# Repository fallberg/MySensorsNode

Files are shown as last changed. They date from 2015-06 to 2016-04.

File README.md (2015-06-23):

# MySensorsNode
My personal [MySensors](http://mysensors.org) Node HW designs.
All designs are released under the [CERN Open Hardware Licence v1.2](http://ohwr.org/cernohl).

External dependencies:
- KiCad
- Non-standard libraries:
  - Mysensors repositories (https://github.com/mysensors-kicad)
  - Walter Lain's KiCad libraries (http://smisioto.no-ip.org/elettronica/kicad/kicad-en.htm)

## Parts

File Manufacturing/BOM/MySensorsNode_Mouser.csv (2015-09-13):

Count | Reference | Value | Footprint | Datasheet | Vendor | Vendor part | Supplier | Supplier part | Supplier link
1 | ANT1 | CONN_01X01 | Wire_Pads:SolderWirePad_single_1-2mmDrill |  |  |  | Missing | Missing | Missing
1 | BT1 | 2.5mm jack | mysensors_connectors:dc_socket-kcswalter | http://www.mouser.com/ds/2/393/rapc712x_cd-371318.pdf | Switchcraft | RAPC712X | Mouser | 502-RAPC712X | http://www.mouser.com/ProductDetail/Switchcraft/RAPC712X/
1 | BT2 | JST | mysensors_connectors:s2b-ph-kl-kcswalter | http://www.farnell.com/datasheets/80564.pdf | JST | S2B-PH-K-S (LF)(SN) | Missing | Missing | Missing
1 | BT3 | Generic | mysensors_connectors:TerminalBlock2.54mmx2-kcswalter | http://www.mouser.com/ds/2/418/NG_CD_282834_C1-665080.pdf | TE Connectivity | 282834-2 | Mouser | 571-282834-2 | http://www.mouser.se/ProductDetail/TE-Connectivity/282834-2/
1 | BT4 | CR123 | mysensors_connectors:CR123_holder | http://www.mouser.com/ds/2/215/051-743208.pdf | Keystone Electronics | 1051 | Mouser | 534-1051 | http://www.mouser.se/ProductDetail/Keystone-Electronics/1051/?Keystone-Electronics%2f1051%2f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
1 | BT5 | 24.5mm | mysensors_connectors:keystone_3009-kcswalter | http://www.mouser.com/ds/2/215/3039-285159.pdf | Keystone Electronics | 3039 | Mouser | 534-3039 | http://se.mouser.com/ProductDetail/Keystone-Electronics/3039/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
1 | C1 | 47uF | Capacitors_Tantalum_SMD:TantalC_SizeC_EIA-6032_HandSoldering | http://www.avx.com/docs/Catalogs/tps.pdf | AVX | TPSC476K016R0350 | Mouser | 581-TPSC476K016R0350 | http://se.mouser.com/ProductDetail/AVX/TPSC476K016R0350/?qs=sGAEpiMZZMuEN2agSAc2pqveSFvydLQ7xWNXjpUWqVg%3d
5 | C2 C10 C12 C13 C14 | 4.7uF | Capacitors_Tantalum_SMD:TantalC_SizeB_EIA-3528_HandSoldering | http://www.avx.com/docs/Catalogs/tps.pdf | AVX | TPSB475K025R0900 | Mouser | 581-TPSB475K025R0900 | http://se.mouser.com/ProductDetail/AVX/TPSB475K025R0900/?qs=sGAEpiMZZMuEN2agSAc2pkIWJcW2hAciBvjiIg4pnBc%3d
2 | C3 C4 | 10uF | Capacitors_Tantalum_SMD:TantalC_SizeA_EIA-3216_HandSoldering | http://www.mouser.com/ds/2/40/f93-221107.pdf | AVX | F931C106MAA | Mouser | 647-F931C106MAA | http://www.mouser.se/ProductDetail/AVX/F931C106MAA/?qs=sGAEpiMZZMuEN2agSAc2puC4lhRhLeolmYomTIpwaLE%3d
2 | C5 C6 | 10uF | Capacitors_SMD:C_1206_HandSoldering | http://www.mouser.com/ds/2/427/vjw1bcbascomseries-223529.pdf | Vishay / Vitramon | VJ1206V106ZXQTW1BC | Mouser | 77-VJ1206V106ZXQTBC | http://se.mouser.com/Search/ProductDetail.aspx
6 | C7 C11 C15 C16 C17 C18 | 0.1uF | Capacitors_SMD:C_1206_HandSoldering | http://www.farnell.com/datasheets/1825494.pdf | MULTICOMP | MCSH31B104K250CT | Mouser | 77-VJ1206Y104KXQPBC | http://se.mouser.com/ProductDetail/Vishay-Vitramon/VJ1206Y104KXQPW1BC/
1 | C8 | C | Resistors_Universal:Resistor_SMD+THTuniversal_0805to1206_RM10_HandSoldering |  | User specific |  | Missing | Missing | Missing
1 | C9 | 0.1uF | Capacitors_SMD:C_1206_HandSoldering | http://www.mouser.com/ds/2/427/vjw1bcbascomseries-223529.pdf | Vishay | VJ1206Y104KXXCW1BC | Mouser | 77-VJ1206Y104KXXCBC | http://www.mouser.se/ProductDetail/Vishay-Vitramon/VJ1206Y104KXXCW1BC/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
7 | JP1 JP3 JP4 JP5 JP6 JP7 JP10 | Jumper_NO_Small | Pin_Headers:Pin_Header_Straight_1x02 | https://www1.elfa.se/data1/wwwroot/assets/datasheets/cgrid_III_90120_eng_dwg.pdf | Wurth Electronics | 61300211121 | Mouser | 710-61300211121 | http://www.mouser.com/ProductDetail/Wurth-Electronics/61300211121/
3 | JP2 JP8 JP9 | JUMPER3 | Pin_Headers:Pin_Header_Straight_1x03 | http://www.mouser.com/ds/2/1/3m_ts0816-349901.pdf | HARWIN | M20-9990346 | Mouser | 517-9611036804AR | http://www.mouser.com/ProductDetail/3M-Electronic-Solutions-Division/961103-6804-AR/
1 | L1 | 4.7uH | Capacitors_SMD:C_0805_HandSoldering | http://www.yuden.co.jp/productdata/catalog/en/wound02_e.pdf | Taiyo Yuden | CBC2012T4R7M | Mouser | 963-CBC2012T4R7M | http://se.mouser.com/ProductDetail/Taiyo-Yuden/CBC2012T4R7M/
1 | P1 | MYSX_1.5 | mysensors_connectors:MYSX_1.5 | http://www.mouser.com/ds/2/181/M20-998-351176.pdf | HARWIN | M20-9981045 | Mouser | 855-M20-9981045 | http://www.mouser.se/ProductDetail/Harwin/M20-9981045/
1 | P2 | CONN_02X03 | Pin_Headers:Pin_Header_Straight_2x03 | http://www.farnell.com/datasheets/1712126.pdf | HARWIN | M20-9980346 | Mouser | 855-M20-9980346 | http://www.mouser.se/ProductDetail/Harwin/M20-9980346/
2 | P3 P4 | CONN_01X03 | Pin_Headers:Pin_Header_Straight_1x03 | http://www.mouser.com/ds/2/1/3m_ts0816-349901.pdf | HARWIN | M20-9993646 | Mouser | 517-9611036804AR | http://www.mouser.com/ProductDetail/3M-Electronic-Solutions-Division/961103-6804-AR/
2 | Q1 Q2 | DMP3056L-7 | Housings_SOT-23_SOT-143_TSOT-6:SOT-23_Handsoldering | http://www.mouser.com/ds/2/115/DMP3056L-526286.pdf | Diodes Incorporated | DMP3056L-7 | Mouser | 621-DMP3056L-7 | http://www.mouser.com/ProductDetail/Diodes-Incorporated/DMP3056L-7/
1 | R1 | 150K | Resistors_SMD:R_0805_HandSoldering | http://www.farnell.com/datasheets/1581132.pdf | Vishay / Dale | CRCW0805150KFKEA | Mouser | 71-CRCW0805-150K-E3 | http://se.mouser.com/ProductDetail/Vishay-Dale/CRCW0805150KFKEA/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
4 | R2 R3 R4 R5 | 10K | Resistors_SMD:R_0805_HandSoldering | https://www1.elfa.se/data1/wwwroot/assets/datasheets/flD-CRCW-e3_data_en.pdf | Vishay | CRCW080510K0FKEA | Mouser | 754-RR1220P-103D | http://se.mouser.com/Search/ProductDetail.aspx
4 | R6 R7 R8 R9 | 56K | Resistors_SMD:R_0805_HandSoldering | https://www1.elfa.se/data1/wwwroot/assets/datasheets/flD-CRCW-e3_data_en.pdf | Panasonic | ERJP06F5602V | Mouser | 754-RR1220P-563D | http://se.mouser.com/ProductDetail/Susumu/RR1220P-563-D/
1 | RV1 | 1M | Potentiometers:Potentiometer_Bourns_3296Y_3-8Zoll_Angular_ScrewUp | http://www.farnell.com/datasheets/1815117.pdf | BOURNS | 3296Y-1-105LF | Mouser | 652-3296Y-1-105LF | http://se.mouser.com/ProductDetail/Bourns/3296Y-1-105LF/?qs=sGAEpiMZZMvygUB3GLcD7sSg8po3Zpo3B4ds1vJ8JQM%3d
1 | U1 | LD1117DT33TR | mysensors_obscurities:d-pak-kcswalter | http://www.st.com/st-web-ui/static/active/en/resource/technical/document/datasheet/CD00000544.pdf | STMicroelectronics | LD1117DT33TR | Mouser | 511-LD1117DT33-TR | http://se.mouser.com/ProductDetail/STMicroelectronics/LD1117DT33TR/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
1 | U2 | TPS61097A | mysensors_handsoldering:SOT-23-5_Handsoldering | http://www.ti.com/lit/ds/symlink/tps61097a-33.pdf | Texas Instruments | TPS61097A-33DBVT | Mouser | 595-TPS61097A-33DBVT | http://www.mouser.com/ProductDetail/Texas-Instruments/TPS61097A-33DBVT/
1 | U3 | ATSHA204A | Housings_SOT-23_SOT-143_TSOT-6:SOT-23_Handsoldering | http://www.mouser.com/ds/2/36/Atmel-8885-CryptoAuth-ATSHA204A-Datasheet-336392.pdf | Atmel | ATSHA204A | Mouser | 566-ATSHA204ASTUCZ-T | http://www.mouser.com/Search/ProductDetail.aspx
1 | U4 | RFM69HW | mysensors_radios:RFM69HW_SMD_ThroughHole_Handsoldering | http://modtronicsaustralia.com/wp-content/uploads/2014/11/RFM69HW-V1.3.pdf | HOPE Microelectronics | RFM69HW | Missing | Missing | Missing
1 | U5 | NRF24L01 | mysensors_radios:NRF24L01 | http://www.farnell.com/datasheets/1697510.pdf | MULTICOMP | 2214S-08SG-85 | Mouser | 517-929975-01-04-RK | http://www.mouser.com/ProductDetail/3M-Electronic-Solutions-Division/929975-01-04-RK/
1 | U6 | AT25DF512C | Housings_SOIC:SOIC-8_3.9x4.9mm_Pitch1.27mm | http://www.mouser.com/ds/2/590/DS-AT25DF512C-030-534014.pdf | Adesto Technologies | AT25DF512C-SSHN-B | Mouser | 988-AT25DF512CSSHN-B | http://www.mouser.com/Search/ProductDetail.aspx
1 | U7 | ArduinoProMini | mysensors_arduino:pro_mini | http://www.arduino.cc/en/uploads/Main/Arduino-Pro-Mini-schematic.pdf | Arduino | Pro Mini (China model) | Missing | Missing | Missing
1 | U8 | Si7021 | Housings_DFN_QFN:DFN-6-1EP_3x3mm_Pitch0.95mm | https://www.silabs.com/Support%20Documents/TechnicalDocs/Si7021-A20.pdf | Silicon Labs | Si7021-A20-GM1 | Mouser | 634-SI7021-A20-GM1 | http://se.mouser.com/ProductDetail/Silicon-Laboratories/Si7021-A20-GM1/
1 | U9 | TPS61221 | Housings_SOT-23_SOT-143_TSOT-6:SC-70-6 | http://www.ti.com/lit/gpn/tps61221 | Texas Instruments | TPS61221DCK | Mouser | 595-TPS61221DCKR | http://www.mouser.se/ProductDetail/Texas-Instruments/TPS61221DCKR/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

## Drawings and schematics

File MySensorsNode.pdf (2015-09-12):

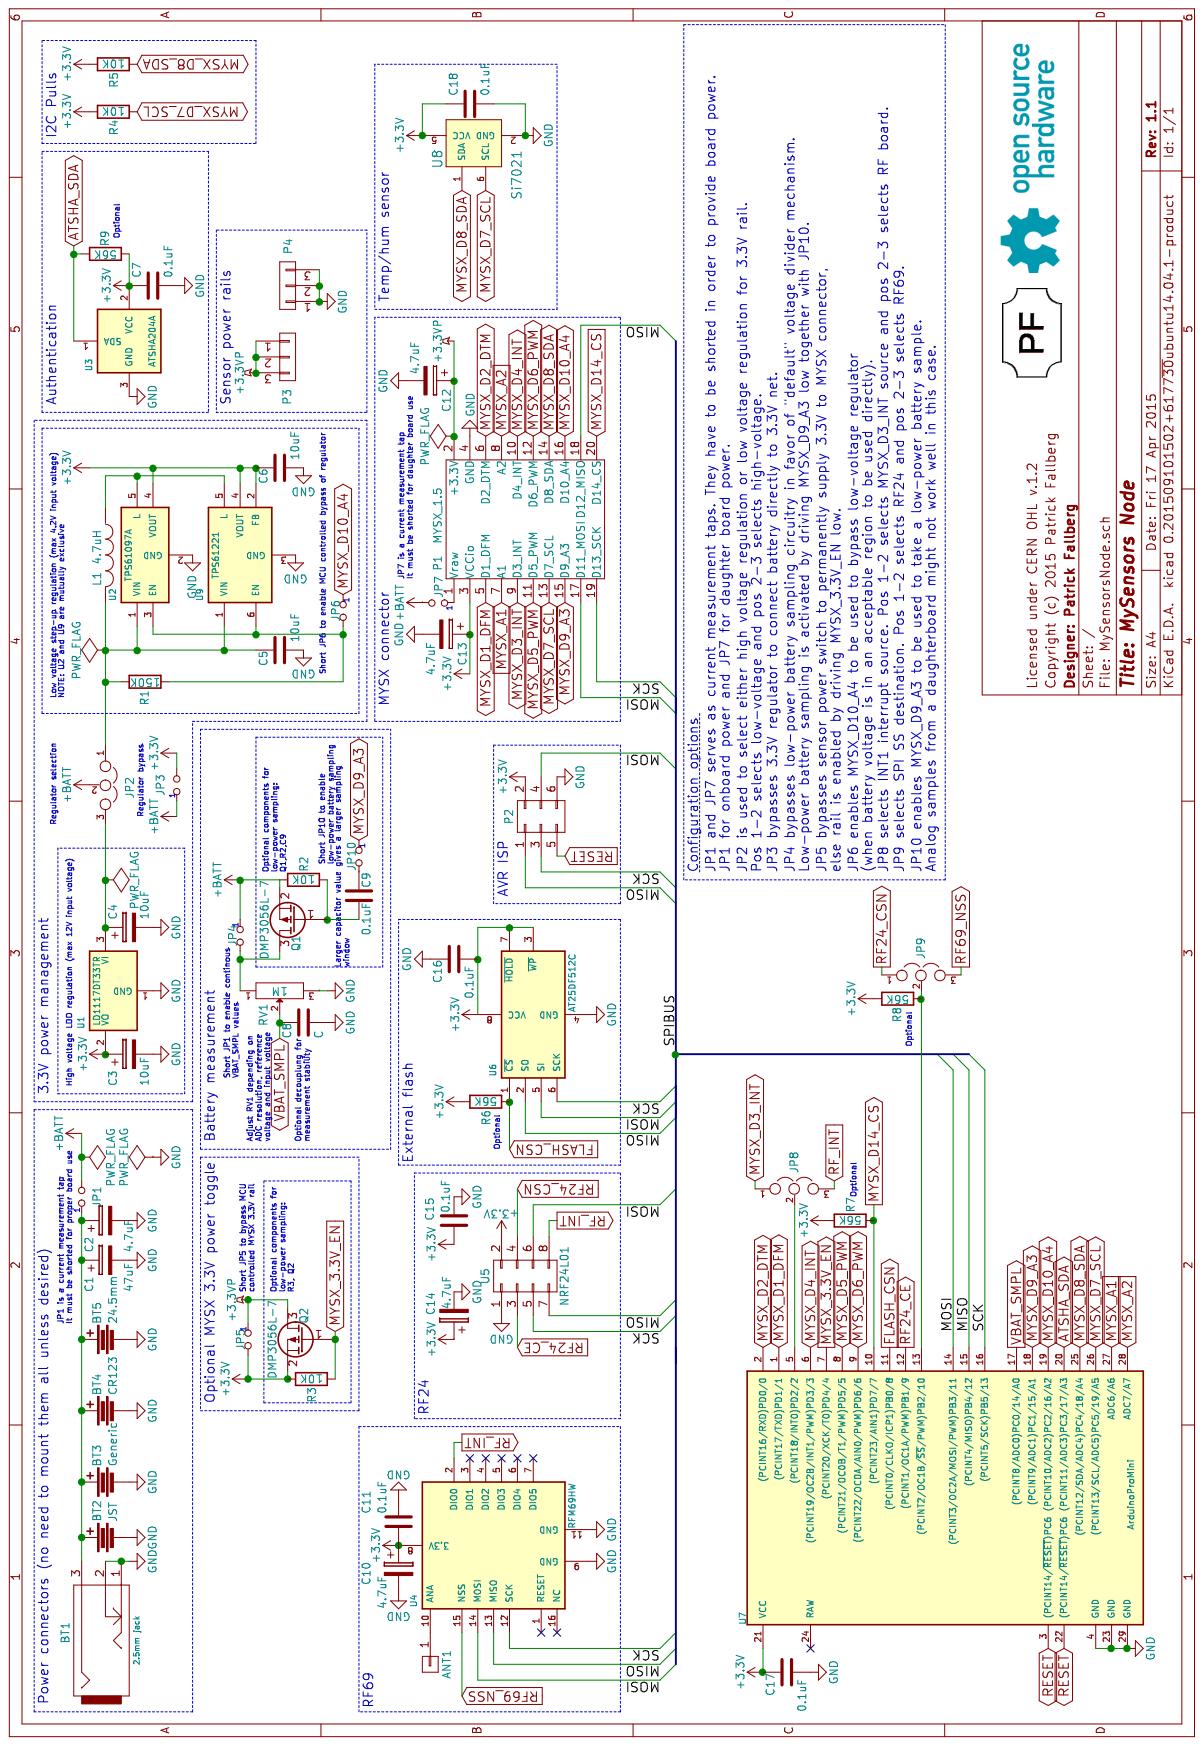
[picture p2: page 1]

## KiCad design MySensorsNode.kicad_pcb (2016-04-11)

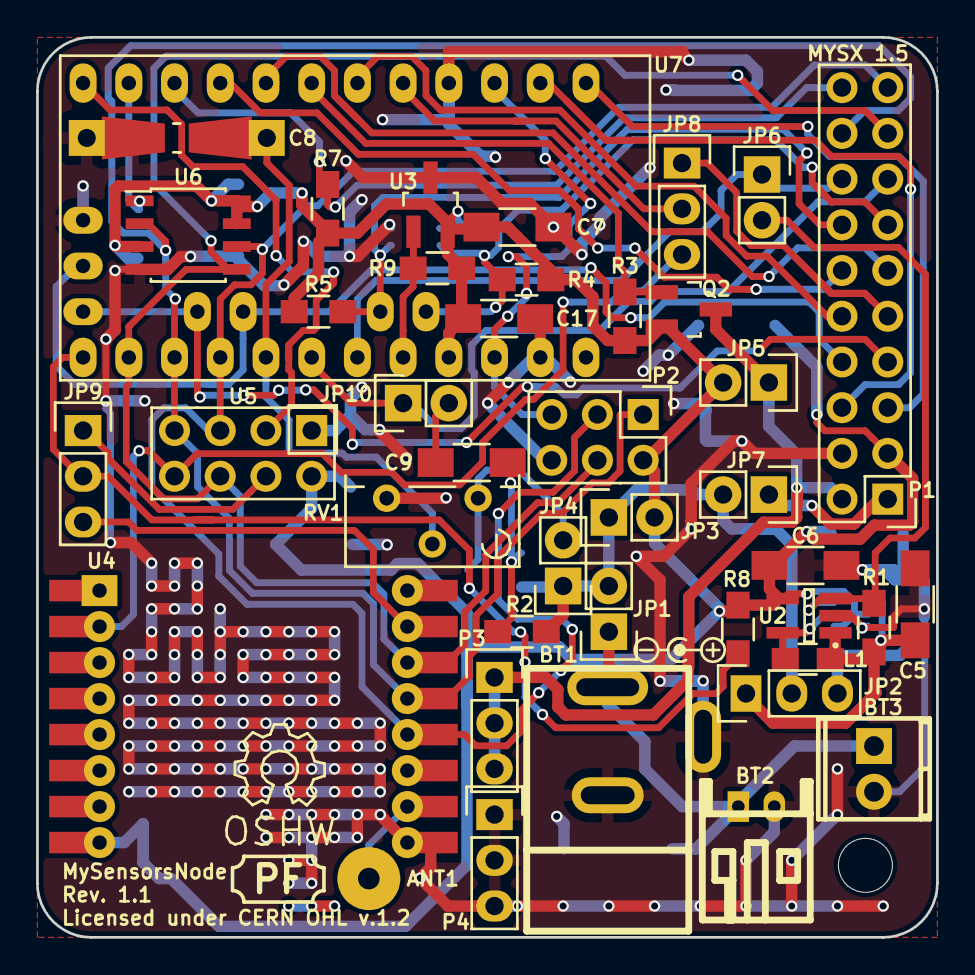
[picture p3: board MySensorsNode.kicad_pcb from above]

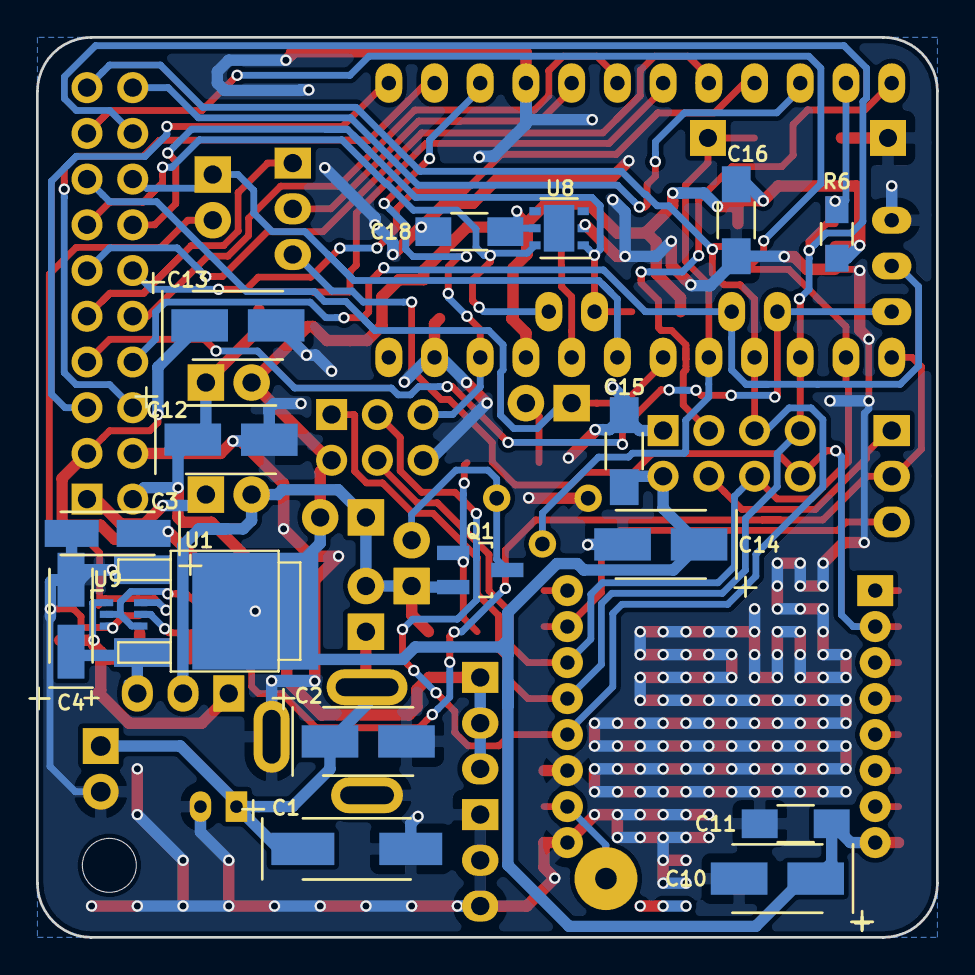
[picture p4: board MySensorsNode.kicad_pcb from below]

Board: 2 copper layers, 50.0 x 50.0 mm, 61 parts (17 on the bottom side), 41 nets.

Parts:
ANT1: CONN_01X01; SolderWirePad_single_1-2mmDrill
BT1: 2.5mm jack; dc_socket-kcswalter
BT2: JST; s2b-ph-kl-kcswalter
BT3: Generic; TerminalBlock2.54mmx2-kcswalter
C1: 47uF; TantalC_SizeC_EIA-6032_HandSoldering
C2, C10, C12, C13, C14: 4.7uF; TantalC_SizeB_EIA-3528_HandSoldering
C3, C4: 10uF; TantalC_SizeA_EIA-3216_HandSoldering
C5, C6: 10uF; C_1206_HandSoldering
C7, C9, C11, C15, C16, C17, C18: 0.1uF; C_1206_HandSoldering
C8: C; Resistor_SMD+THTuniversal_0805to1206_RM10_HandSoldering
HOLE1: MountingHole_3mm
JP1, JP3, JP4, JP5, JP6, JP7, JP10: Jumper_NO_Small; Pin_Header_Straight_1x02
JP2, JP8, JP9: JUMPER3; Pin_Header_Straight_1x03
L1: 4.7uH; C_0805_HandSoldering
OSHW_LOGO: Symbol_OSHW-Logo_SilkScreen
P1: MYSX_1.5
P2: CONN_02X03; Pin_Header_Straight_2x03
P3, P4: CONN_01X03; Pin_Header_Straight_1x03
PLUG_SPEC: LOGO; Logo_silk_polarity_center_5x1.4mm
Q1, Q2: DMP3056L-7; SOT-23_Handsoldering
R1: 150K; R_0805_HandSoldering
R2, R3, R4, R5: 10K; R_0805_HandSoldering
R6, R7, R8, R9: 56K; R_0805_HandSoldering
RV1: 1M; Potentiometer_Bourns_3296Y_3-8Zoll_Angular_ScrewUp
U1: LD1117DT33TR; d-pak-kcswalter
U2: TPS61097A; SOT-23-5_Handsoldering
U3: ATSHA204A; SOT-23_Handsoldering
U4: RFM69HW; RFM69HW_SMD_ThroughHole_Handsoldering
U5: NRF24L01
U6: AT25DF512C; SOIC-8_3.9x4.9mm_Pitch1.27mm
U7: ArduinoProMini; pro_mini
U8: Si7021; DFN-6-1EP_3x3mm_Pitch0.95mm
U9: TPS61221; SC-70-6

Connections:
+3.3VP: C12.1, JP5.1, P1.2, P3.1, P3.2, P3.3, Q2.3
+3V3: C3.1, C6.1, C7.1, C10.1, C11.2, C13.1, C14.1, C15.2, C16.2, C17.1, C18.1, JP3.2, JP5.2, P1.3, P2.2, Q2.2, R3.2, R4.2, R5.2, R6.2, R7.2, R8.1, R9.2, U1.2, U2.4, U3.2, U4.8, U5.2, U6.3, U6.7, U6.8, U7.21, U8.5, U9.2, U9.4
+BATT: JP1.2, JP2.2, JP3.1, JP4.1, JP7.2, Q1.2, R2.2
/MISO: P1.18, P2.1, U4.13, U5.7, U6.2, U7.15
/MOSI: P1.17, P2.4, U4.14, U5.6, U6.5, U7.14
/SCK: P1.19, P2.3, U4.12, U5.5, U6.6, U7.16
ATSHA_SDA: R9.1, U3.1, U7.20
FLASH_CSN: R6.1, U6.1, U7.11
GND: BT1.1, BT1.2, BT2.2, BT3.2, C1.2, C2.2, C3.2, C4.2, C5.2, C6.2, C7.2, C8.2, C10.2, C11.1, C12.2, C13.2, C14.2, C15.1, C16.1, C17.2, C18.2, P1.4, P2.6, P4.1, P4.2, P4.3, RV1.3, U1.1, U2.2, U3.3, U4.9, U4.11, U5.1, U6.4, U7.4, U7.23, U7.29, U8.2, U9.3
MYSX_3.3V_EN: Q2.1, R3.1, U7.7
MYSX_A1: P1.7, U7.27
MYSX_A2: P1.8, U7.28
MYSX_D1_DFM: P1.5, U7.1
MYSX_D2_DTM: P1.6, U7.2
MYSX_D3_INT: JP8.1, P1.9
MYSX_D4_INT: P1.10, U7.6
MYSX_D5_PWM: P1.11, U7.8
MYSX_D6_PWM: P1.12, U7.9
MYSX_D7_SCL: P1.13, R4.1, U7.26, U8.6
MYSX_D8_SDA: P1.14, R5.1, U7.25, U8.1
MYSX_D9_A3: JP10.1, P1.15, U7.18
MYSX_D10_A4: JP6.1, P1.16, U7.19
MYSX_D14_CS: P1.20, R7.1, U7.10
unnamed: ANT1.1, U4.10
unnamed: BT1.3, BT2.1, BT3.1, C1.1, C2.1, JP1.1
unnamed: C4.1, JP2.3, U1.3
unnamed: C5.1, JP2.1, L1.2, R1.1, U2.1, U9.1
unnamed: C9.1, JP10.2
unnamed: C9.2, Q1.1, R2.1
unnamed: JP4.2, Q1.3, RV1.1
unnamed: JP6.2, R1.2, U2.3, U9.6
unnamed: JP7.1, P1.1
unnamed: JP8.2, U7.5
unnamed: JP9.2, R8.2, U7.13
unnamed: L1.1, U2.5, U9.5
RESET: P2.5, U7.3, U7.22
RF24_CE: U5.3, U7.12
RF24_CSN: JP9.1, U5.4
RF69_NSS: JP9.3, U4.15
RF_INT: JP8.3, U4.2, U5.8
VBAT_SMPL: C8.1, RV1.2, U7.17

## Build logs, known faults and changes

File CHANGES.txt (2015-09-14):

commit c6829e1e322eb0ecf867edcd6b73e424e8df0c89
Author: Patrick Fallberg <patrick@fallberg.net>
Date:   Sun Sep 13 15:36:56 2015 +0200

    Corrected Mouser/Farnell parts for P2

commit 2b0d06d92dfd4355a7a4b18cb5ec9ce1f207d5c6
Author: Patrick Fallberg <patrick@fallberg.net>
Date:   Sat Sep 12 22:18:08 2015 +0200

    Removed origin-symbol from board outlines

commit 1c8365d9faff273dc4cebe651df270a5b05ed6fa
Author: Patrick Fallberg <patrick@fallberg.net>
Date:   Sat Sep 12 22:10:38 2015 +0200

    Created manufacturing outputs
    
    Also created DirtyPCBs-formatted archives.
    Fixes #9

commit af362b0fcdb8be146da8d00798e79c5897116803
Author: Patrick Fallberg <patrick@fallberg.net>
Date:   Sat Sep 12 22:02:41 2015 +0200

    Minor layout beautifications

commit 6da535b47e0d930e4cade6ed8c1804b414268bb9
Author: Patrick Fallberg <patrick@fallberg.net>
Date:   Sat Sep 12 17:33:58 2015 +0200

    Created BOM(s)
    
    Fixes #10

commit 09b7c4b18d3ffa5ed8908088ca1046db3e48c771
Author: Patrick Fallberg <patrick@fallberg.net>
Date:   Sat Sep 12 17:27:01 2015 +0200

    Created a BOM generator script for this project
    
    The BOM generator (verified on KiCad for Linux) parses the netllist
    data and outputs 9 BOM files:
    MySensorsNode_Full.txt - Full BOM with all suppliers
    MySensorsNode_Cheapest.txt - BOM with the cheapest supplier
    MySensorsNode_AliExpress.txt - BOM with all parts available from AliExpress
    MySensorsNode_Digi-Key.txt - BOM with all parts available from Digi-Key
                                 This file is supported by Digi-Keys Text File
                                 Import tool.
    MySensorsNode_eBay.txt - BOM with all parts available from eBay
    MySensorsNode_Elfa.txt - BOM with all parts available from Elfa
                             This file is suppored by Elfas Own list upload tool.
    MySensorsNode_Farnell.txt - BOM with all parts available from Farnell
    MySensorsNode_Mouser.csv - BOM with all parts available from Mouser
                               This file is supported by Mousers BOM import tool.
    MySensorsNode_RS.txt - BOM with all parts available from RS Components
    
    Usage:
    Add plugin in the Bill of Material tool in the KiCad schematic editor.
    Command line is:
    python "<path to pf_bom_orders.py>" "%I" "%P/Manufacturing/BOM/%B"

commit a0b7d2081370d753c179b53b6fe635f4e56f8792
Author: Patrick Fallberg <patrick@fallberg.net>
Date:   Sat Sep 12 17:14:41 2015 +0200

    Completed sourcing details of all components
    
    Sourcing data is organized in the following way:
    Supplier1 - The primary supplier (also the cheapest)
    Supplier1 part - The primary supplier part number
    Supplier1 link - Link to the part on the suppliers homepage
    
    The same goes for Supplier2 to 5.
    All parts also have a Vendor and Vendor part field to identify
    a vendor for each part.
    
    Fixes #6

commit dedd2f74219450baf48360123f8e6970bc3806d9
Author: Patrick Fallberg <patrick@fallberg.net>
Date:   Sat Sep 12 12:29:52 2015 +0200

    Updated CR123 battery holder footprint
    
    Fixes #11

commit ceb92c99b859bb8fba81d5ead6944f00e74a0db8
Author: Patrick Fallberg <patrick@fallberg.net>
Date:   Thu Sep 10 17:14:51 2015 +0200

    Added more sourcing details
    
    Also minor schematic beautifications

commit c3afbb278e0b595ffe8860ce40d635c5186febf4
Author: Patrick Fallberg <patrick@fallberg.net>
Date:   Tue Sep 1 23:47:13 2015 +0200

    Added a step-up reg and some sourcing details
    
    Added TI TPS61221 (3.3V fixed) as an alternative to TPS61097A.
    Also added some more sourcing details to some components in the
    schematic.

commit a9de2d0fda3e2e20fb438053d0ed1dc1a1a9444a
Author: Patrick Fallberg <patrick@fallberg.net>
Date:   Mon Aug 31 10:47:24 2015 +0200

    Moved BT5 to make more room for mounting screw

commit 9ecaa06f57022bd6a6c9af58877cf1eb74a005dd
Author: Patrick Fallberg <patrick@fallberg.net>
Date:   Mon Aug 31 10:37:13 2015 +0200

    Created layout for LE-BOX-0028
    
    Fixes #8

commit 912072cc9c9a7d4f22a4622eae9dfa80e3f58186
Author: Patrick Fallberg <patrick@fallberg.net>
Date:   Mon Aug 31 10:36:57 2015 +0200

    Adjusted track width of some power-nets

commit 78a33fa561b48c61317e8972cb7ff54830cba78a
Author: Patrick Fallberg <patrick@fallberg.net>
Date:   Fri Aug 28 01:39:02 2015 +0200

    Radio module footprints updated to latest revisions

commit a60b3c3cf31e2c5438b26684cd984a3680335189
Author: Patrick Fallberg <patrick@fallberg.net>
Date:   Fri Aug 28 01:30:28 2015 +0200

    Created 5x5 cm layout
    
    BT4 and BT5 are omitted in this layout.
    Fixes #7.

commit 4c2da7ea8109a5d2c6d167f7a072add6e8394303
Author: Patrick Fallberg <patrick@fallberg.net>
Date:   Mon Aug 24 19:43:32 2015 +0200

    Updated U1 footprint
    
    U1 footprint is now available in the mysensors-kicad repository

commit 3480dfd4274b0d1f4f9a5721b6239103e7c1e26c
Author: Patrick Fallberg <patrick@fallberg.net>
Date:   Mon Aug 24 15:50:53 2015 +0200

    Minor beautifications and updated CHANGES.txt

commit 3ced118320753cb000ec8ca2e32348e9311f97a1
Author: Patrick Fallberg <patrick@fallberg.net>
Date:   Mon Aug 24 15:47:35 2015 +0200

    Updated .gitignore to filter some autogenerated files

commit 0c326c48fd0285459b0b63c1a5e7cb755e61c353
Author: Patrick Fallberg <patrick@fallberg.net>
Date:   Fri Apr 24 12:14:06 2015 +0200

    Rev. 1.1 of my generic MySensors node
    
    * Added resistor to terminate REG_BYPASS to default 'on' (fixes #2)
    * Added extra RF bypass capacitors (fixes #5)
    * Updated RF69 footprint to have sligtly wider space between holes
    * Added optional pull-ups to CS signals on SPI devices (fixes #3)
    * Reversed polarity of CON1 to fit battery default pinout (fixes #1)
    * Sensor pin connector swapped in favor of MYSX 1.5 connector
    * More battery options
    * Discarded 5V regulator and added a different 3.3V reg for 12V input (fixes #4)
    * Created layout for Superbat box BOX-2252
    
    Things left to do:
    * Update schematic with full sourcing details
    * Create 5x5cm layout (default)
    * Create Superbat box LE-BOX-0028 layout
    * Create manufacturing outputs
    * Create BOM(s)

commit d8ca8d24746c1e1fc214979bb362ea2246e7586e
Author: Patrick Fallberg <patrick@fallberg.net>
Date:   Fri Apr 24 12:14:06 2015 +0200

    First version of my generic MySensors node
    
    Features:
    - Switchable battery level measurement
    - By-passable 3.3V step-up regulator
    - Possibility to disable sensor power rail
    - Optional additional 5V step-up regulator for sensors
    - 2.5mm DC jack power supply footprint
    - 2mm pitch JST connector for LiPo batteries
    - Both RF24 and RF69 footprints and possibility for interrupt connectivity
    - External SPI flash
    - AVR ISP programming header
    - ATSHA204A authenticatior footprint
    - On-board I2C pullups
    - On-board sensor ports (all with 3.3 and 5V rails):
      - 1 PWM enabled sensor port
      - 2 HW interrupt sensor ports (1 optionally taken by radio)
      - 2 generic I/O sensor ports that also provide HW UART
      - 1 SPI header
      - 2 Analog sensor ports
      - 2 I2C sensor ports
    
    Known issues:
    - The layout of CON1 is incorrect with respect to normal battery
      connectors so battery polarity will be reversed. Do NOT connect
      a battery with JST connector to this board (Rev 1.0).
    
    - 3.3V regulator has an unterminated EN-signal. That means it could
      start up in "off" state which mean that if battery level is too high
      (>4.1V) SPI flash could fry. If battery level is too low (<1.8V),
      MCU might not start in order to enable the regulator.
      A workaround if this situation is undesirable is to solder a pull-up
      resistor between REG_BYPASS and +BATT signals.
    
    - Pull-ups are missing on SPC CS signals which may lead to undetermined
      behaviour on some SPI devices.
    
    - The 5V regulator does not work proerly when cascaded with the 3.3v regulator.
      It should not be mounted on this board, or the board should be rewired to connect
      the 5V regulator directly to +BATT.
    
    - DC input is inadequatly bypassed for wall warts. It is recommended to add one or two
      additional capacitors to suppres input noise (~47 to ~470uF).

commit bbee155028989935a90c55b6a817a3273476bcd4
Author: Patrick Fallberg <patrick@fallberg.net>
Date:   Tue Jun 23 15:17:21 2015 +0200

    Update README with dependencies

commit 18222d58819bbb0e3357e55b16a7755df9d50e5b
Author: Patrick Fallberg <patrick@fallberg.net>
Date:   Sun Jun 7 20:02:16 2015 +0200

    Added CERN Open Hardware Licence v1.2 license text

commit 9b487e73d7a971a68065ff828a7cadb89106429c
Author: Patrick Fallberg <patrick@fallberg.net>
Date:   Sat Jun 6 11:23:07 2015 +0200

    Added .gitignore to filter autogenerated backups

commit 86491ca7ff41641f8fa50d24bd5d19b52cb83c9e
Author: Patrick Fallberg <fallberg@users.noreply.github.com>
Date:   Mon Apr 13 16:52:03 2015 +0200

    Initial commit

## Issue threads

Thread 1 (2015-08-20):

Mirrored JST connector

fallberg, 2015-08-20:
The layout of CON1 is incorrect with respect to normal battery connectors so battery polarity will be reversed. Do NOT connect a battery with JST connector to this board (Rev 1.0).

Closed 2015-08-21.

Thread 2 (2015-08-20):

3.3V regulator has an unterminated EN-signal

fallberg, 2015-08-20:
That means it could start up in "off" state which mean that if battery level is too high (>4.1V) SPI flash could fry. If battery level is too low (<1.8V), MCU might not start in order to enable the regulator. A workaround if this situation is undesirable is to solder a pull-up resistor between REG_BYPASS and +BATT signals.

Closed 2015-08-21.

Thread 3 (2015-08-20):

Pull-ups are missing on SPI CS signals

fallberg, 2015-08-20:
This may lead to undetermined behavior on some SPI devices.

Closed 2015-08-21.

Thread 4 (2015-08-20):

The 5V regulator does not work properly

fallberg, 2015-08-20:
The 5V regulator does not work properly when cascaded with the 3.3v regulator.
It should not be mounted on this board, or the board should be rewired to connect the 5V regulator directly to +BATT.

Closed 2015-08-21.

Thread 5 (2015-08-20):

DC input is inadequatly bypassed for wall warts

fallberg, 2015-08-20:
It is recommended to add one or two additional capacitors to suppress input noise (~47 to ~470uF).

Closed 2015-08-21.

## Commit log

2015-06-06 Added .gitignore to filter autogenerated backups
2015-06-25 First version of my generic MySensors node
    Features:
    - Switchable battery level measurement
    - By-passable 3.3V step-up regulator
    - Possibility to disable sensor power rail
    - Optional additional 5V step-up regulator for sensors
    - 2.5mm DC jack power supply footprint
    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
    [MySensorsNode.csv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]
2015-08-21 Rev. 1.1 of my generic MySensors node
    * Added resistor to terminate REG_BYPASS to default 'on' (fixes #2)
    * Added extra RF bypass capacitors (fixes #5)
    * Updated RF69 footprint to have sligtly wider space between holes
    * Added optional pull-ups to CS signals on SPI devices (fixes #3)
    * Reversed polarity of CON1 to fit battery default pinout (fixes #1)
    * Sensor pin connector swapped in favor of MYSX 1.5 connector
    * More battery options
    * Discarded 5V regulator and added a different 3.3V reg for 12V input (fixes #4)
    * Created layout for Superbat box BOX-2252
    Things left to do:
    * Update schematic with full sourcing details
    * Create 5x5cm layout (default)
    * Create Superbat box LE-BOX-0028 layou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
    [BOX-2252.kicad_pcb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]
2015-08-24 Updated .gitignore to filter some autogenerated files
2015-08-24 Minor beautifications and updated CHANGES.txt
    [BOX-2252.kicad_pcb, MySensorsNode.sch]
2015-08-24 Updated U1 footprint
    U1 footprint is now available in the mysensors-kicad repository
    [BOX-2252.kicad_pcb, MySensorsNode.sch]
2015-08-27 Created 5x5 cm layout
    BT4 and BT5 are omitted in this layout.
    Fixes #7.
    [MySensorsNode.kicad_pcb]
2015-08-27 Radio module footprints updated to latest revisions
    [BOX-2252.kicad_pcb, MySensorsNode.kicad_pcb]
2015-08-31 Adjusted track width of some power-nets
    [BOX-2252.kicad_pcb]
2015-08-31 Created layout for LE-BOX-0028
    Fixes #8
    [LE-BOX-0028.kicad_pcb]
2015-08-31 Moved BT5 to make more room for mounting screw
    [LE-BOX-0028.kicad_pcb]
2015-09-01 Added a step-up reg and some sourcing details
    Added TI TPS61221 (3.3V fixed) as an alternative to TPS61097A.
    Also added some more sourcing details to some components in the
    schematic.
    [BOX-2252.kicad_pcb, LE-BOX-0028.kicad_pcb, MySensorsNode.kicad_pcb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]
2015-09-10 Added more sourcing details
    Also minor schematic beautifications
    [BOX-2252.kicad_pcb, MySensorsNode.sch]
2015-09-12 Updated CR123 battery holder footprint
    Fixes #11
    [BOX-2252.kicad_pcb, LE-BOX-0028.kicad_pcb, MySensorsNode.kicad_pcb]
2015-09-12 Completed sourcing details of all components
    Sourcing data is organized in the following way:
    Supplier1 - The primary supplier (also the cheapest)
    Supplier1 part - The primary supplier part number
    Supplier1 link - Link to the part on the suppliers homepage
    The same goes for Supplier2 to 5.
    All parts also have a Vendor and Vendor part field to identify
    a vendor for each part.
    Fixes #6
    [MySensorsNode.sch]
2015-09-12 Created a BOM generator script for this project
    The BOM generator (verified on KiCad for Linux) parses the netllist
    data and outputs 9 BOM files:
    MySensorsNode_Full.txt - Full BOM with all suppliers
    MySensorsNode_Cheapest.txt - BOM with the cheapest supplier
    MySensorsNode_AliExpress.txt - BOM with all parts available from AliExpress
    MySensorsNode_Digi-Key.txt - BOM with all parts available from Digi-Key
    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
2015-09-12 Created BOM(s)
    Fixes #10
    [MySensorsNode_Mouser.csv]
2015-09-12 Minor layout beautifications
    [BOX-2252.kicad_pcb, LE-BOX-0028.kicad_pcb, MySensorsNode.kicad_pcb]
2015-09-12 Created manufacturing outputs
    Also created DirtyPCBs-formatted archives.
    Fixes #9
    [BOX-2252-B_Cu.gbr, BOX-2252-B_Mask.gbr, BOX-2252-B_SilkS.gbr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]
2015-09-12 Removed origin-symbol from board outlines
    [BOX-2252.kicad_pcb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]
2015-09-13 Corrected Mouser/Farnell parts for P2
    [MySensorsNode.sch, MySensorsNode_Mouser.csv]
2016-04-11 Adjusted 3d model search paths
    [BOX-2252.kicad_pcb, LE-BOX-0028.kicad_pcb, MySensorsNode.kicad_pcb]

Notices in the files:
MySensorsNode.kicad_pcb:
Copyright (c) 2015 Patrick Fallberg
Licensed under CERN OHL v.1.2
